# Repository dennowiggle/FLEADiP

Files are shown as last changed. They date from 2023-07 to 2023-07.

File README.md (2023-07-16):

# FLEADiP
FLEADiP is a compatiable add-on board for the Z80 Retro! project.

## Description
This project is an FPGA Logic Engine And Display Processor add-on board that fits the form factor of the [Z80 Retro! project by John Winans](https://github.com/Z80-Retro).

It has VGA, HDMI, two Atari 2600 compatible joystick ports, and user I/O expansion pin headers. 

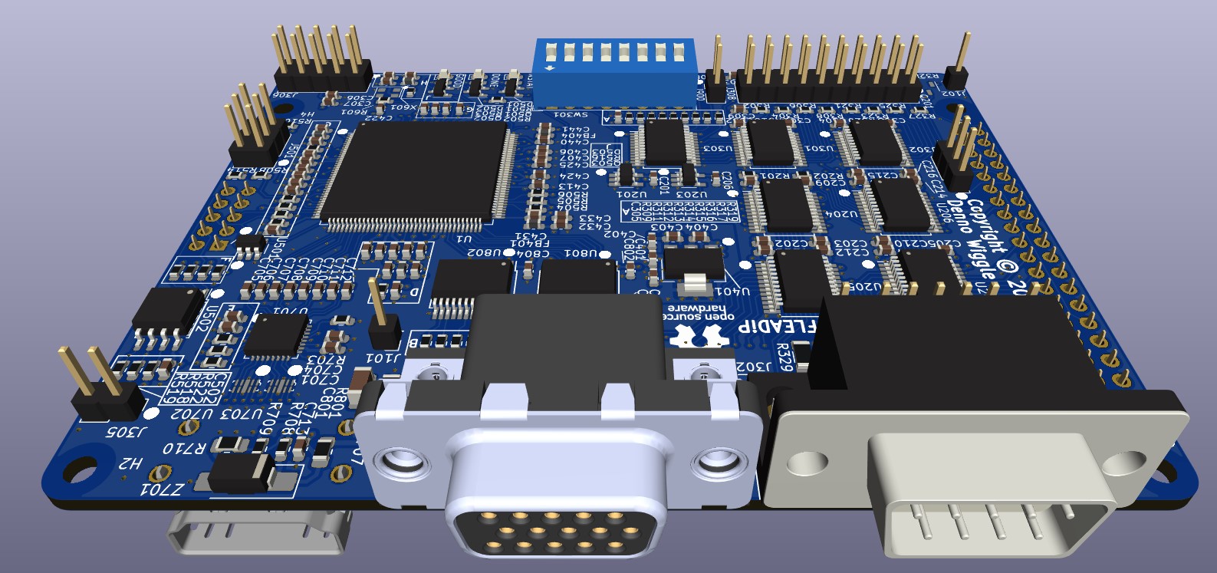
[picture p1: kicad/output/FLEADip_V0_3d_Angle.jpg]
FLEADiP Board Image FPGA Logic Engine And Video Processor


## Board design 
The board design is based around an Efinix Trion T20 FPGA in a QFP144 package. The HDMI output is driven by a PTN3366 IC that converts the LVDS from the FPGA into a true TMDS signal.

The VGA, HDMI, input header, and joystick ports are completely buffered to protect the FPGA. The user I/O port is unbuffered to give plenty of options for add-on creations.

The HDMI socket is on the back side of the board and allowance must be made for the type of board that is underneath. If there is not a good fit, a spacer board can be added.

## FPGA logic
The FPGA logic uses [Matthew Hagerty's F18A core](https://github.com/dnotq/f18a) so that code is compatible with the Z80 Retro! [2068-Z80-TMS9118 project board](https://github.com/Z80-Retro/2068-Z80-TMS9118). 

The HDMI logic on the FPGA uses the DVI code design from [Randi Rossi's VicII-Kawari project](https://github.com/randyrossi/vicii-kawari).

The FPGA image is stored on a 4MByte W25Q32JVSS Flash memory. There is both a SPI and JTAG programming header on the right side of the board. The board may be programmed using an FT232H module with the Efinix Efinity Progrrammer tool, or using another Z80 Retro! add on board, the - ESP32 Interface and Programmer with WiFi board (link coming) which was designed to fit below this one (no HDMI connector fit concerns).

A Trion FPGA with part number T20Q144C3 was used for bringup and testing of FLEADiP rev 0. This was a C3 timing part. A C4 or I4 part is preferred as they provide improved timing margin.

# Z80 I/O Port Addresses
| I/O Address | Function |
|---|---|
| 0x50 | FPGA address register address |
| 0x51 | FPGA data registers (not all are writable)  |
| 0x80 | Video Display Processor |
| 0x81 | Video Display Processor |
| 0xA8 | Joystick 0 (Z80 Retro! legacy address) |
| 0xA9 | Joystick 1 (Z80 Retro! legacy address) |

# FPGA Registers
Full details listed [in the VHDL code](fpga/src/wtm/wtm_z80Interface.vhd)
| Register Address  | Register Function | Read / Write |
|---|---| --- |
| 0 | FPGA Version | R |
| 1 | R/W Test Register  | R/W |
| 2 | PLL Lock | R |
| 3 | Config switch | R |
| 4 | Joystick 0 | R |
| 5 | Joystick 1 | R |
| 6 | HDMI control | R/W |
| 6 | Interrupt | R |

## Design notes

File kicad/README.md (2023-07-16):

# FLEADiP
FLEADiP is a compatiable add-on board for the Z80 Retro! project

## Description
This project is an FPGA Logic Engine And Display Processor add-on board that fits the form factor of the [Z80 Retro! project by John Winans](https://github.com/Z80-Retro).

## Top View
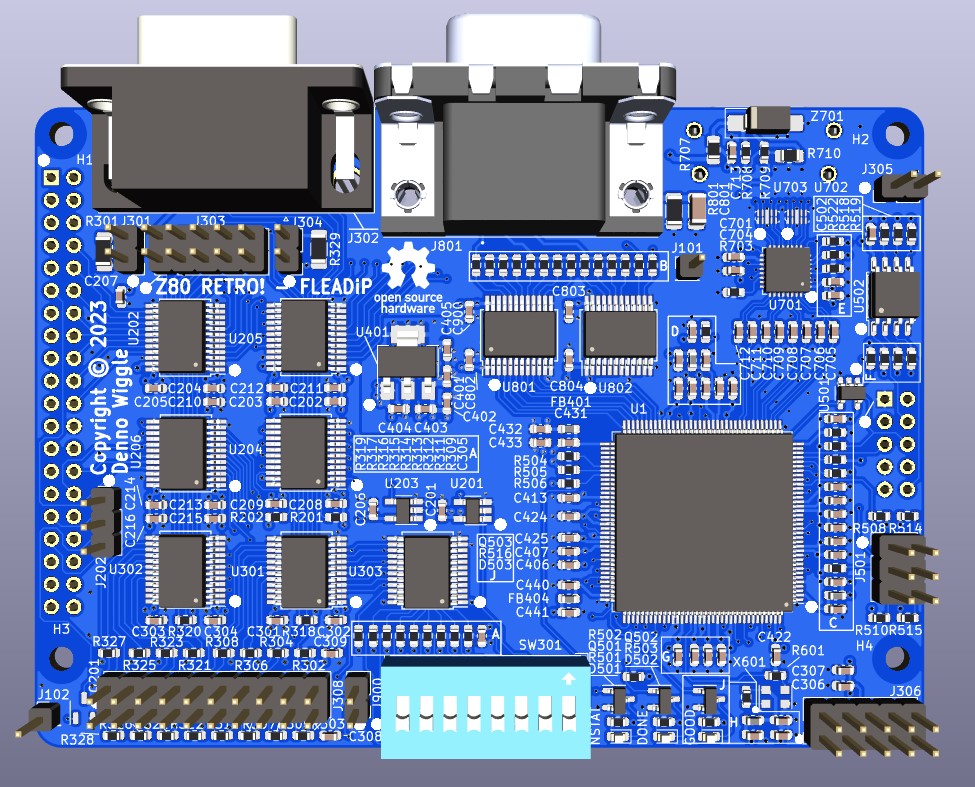
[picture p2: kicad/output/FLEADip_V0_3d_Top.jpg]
FLEADiP Top View Board Image Top View of FPGA Logic Engine And Video Processor


## Bottom View
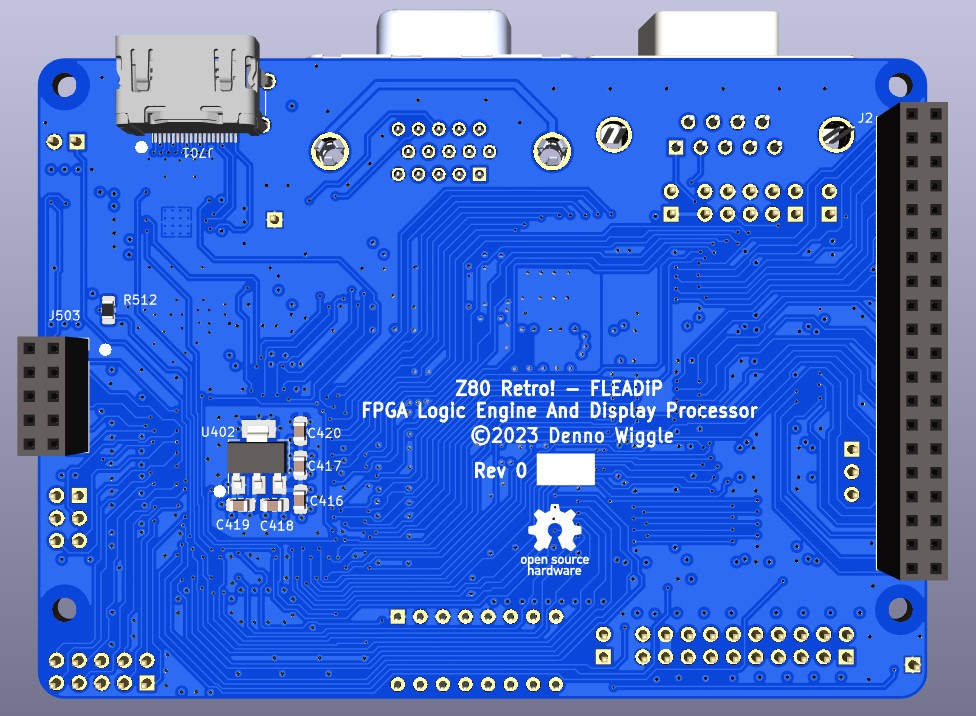
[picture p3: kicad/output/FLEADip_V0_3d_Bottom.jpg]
FLEADiP Bottom View Board Image Bottom View of FPGA Logic Engine And Video Processor


## FLEADiP Board Rev 0.0 Release Notes

1. The 'output' directory contains the BOM, netlist, and PDF schematic.

2. Board design used KiCad 7.0.2.

3. The HDMI connector is on the bottom side of the board so that there is no P/N signal swap, at least for rev 0 PCB. This means the card doesn't fit right above the Z80 Retro! CPU board unless a spacer board is added or the HDMI connector is not installed. The board was designed with the intent to use the ESP32 programmer board underneath FLEADiP which does have space for the connector.
   
   A future spin could move the HDMI connector to the top side, with swapping all P/N traces. This may work right away with no hdl code change, but if it does not the logic should be inverted in the HDL code to address this.
   
4. The silkscreen circle pin 1 marker for SW301, the 16 pin configuration switch is in the wrong position. The copper layout is fine, 
    - pin 1 is in the opposite corner to that marked - top right as viewed from the front board edge.

5. J503 2x5 right-angle programming connector should be installed on the top side of the board.
   - The silkscreen is marked on the back side, opposite to where the connector should be installed on.
   - The Bottom Side View image shows a vertical receptacle connector installed when it is in fact a right-angle header on the Top Side.

7. To program an image to the FPGA FLASH you can use a FT232H module with the Efinity FPGA SW tool programmer. 
   - I tested a $12 one from Amazon  https://www.amazon.com/dp/B09XTF7C1P:
   - Pin connections are as follows:

| Signal |  FT232H Module Pin  | FLEADiP Location |
| --- | --- | --- |
| SPI_CLK | AD1 | J503.2 |
| SPI_MOSI | AD0 | J503.8 |
| SPI_MISO | AD2 | J503.10 |
| SPI_CS_N | AD3 | J503.4 |
| MOUSE_RESET_N | AD4 | J503.6 |
| MOUSE_CDONE | AD5 | J503.5 |
| GND | Module Specific | J503.9 |
  
7. Efinity Programmer tool settings
    - With the FT232H module the USB target should be USB <-> Serial Convertor
    - Active mode
    - Starting address 0x0
    - Check erase before programming
    - Check verify after programming
    - Uses a hex file image
  
8. The board can also be programmed with the "ESP32 Programmer and WiFi" Z80 Retro! add on board which offers console xmodem and web based upload options for programming files.

9. The second Joystick port uses a 10 pin header J303 and is designed for a 10pin header to female DB9 cable with a gender 
   changer added. That way it's just using another Z80 Retro! console cable with addition of DB9 gender changer rather than 
   a totally new cable.
    - To use a 2x5 header to male DB9 cable the wires on the header need to swap pin columns.
      This method was tested with cable https://www.amazon.com/dp/B0BGQ96LX5

10. 1x2 pin headers that supply 5V if a jumper is installed on the joystick ports should be no stuff for normal operation.
    - If you want to supply 5V on DB9 pin 5 then soldering a wire is preferred as clearances of 1x2 to 2x5 headers are tight for DB9 cables made with IDC headers and 2 pin headers with jumpers installed.
    - To use a 2x5 cable with 1x2 jumpers installed use a 2x5 to DB9 cable with a narrow 2x5 receptacle. 
    - J301, J305 = no stuff for normal use.

11. The second joystick fire/button2 and 5V options are wired per MSX joystick form factor. 
     - Do not plug another type of 2 button joystick such as for C64 or Atari 
       especially if 5V is expected on a pin other than pin 5.
     - One button Atari 2600 compatible joysticks are supported.

12. The schematic design and BOM uses a T20QFP144 device with C3 timing. It is recommended to switch to a C4 part as it has significantly more timing margin in the logic design. DigiKey part number is 2134-T20Q144C4-ND. An I4 device is also a good choice .

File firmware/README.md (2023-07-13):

# Test Program

A simple Z80 assembly test program to access the FLEADiP FPGA registers.

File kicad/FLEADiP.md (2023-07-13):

# FLEADiP.kicad_sch

## 7/9/2023 3:29:13 PM

## Eeschema 7.0.2

## Component Count:224

Ref | Qty | Value | Digikey | Datasheet | Description
----|-----|-------|---------|-----------|------------
C201, C204, C205, C206, C208, C209, C211, C212, C213, C214, C301, C302, C303, C304, C305, C306, C308, C403, C404, C407, C408, C409, C410, C411, C412, C413, C414, C415, C422, C423, C424, C425, C426, C427, C428, C429, C430, C431, C432, C435, C437, C438, C439, C440, C441, C501, C502, C601, C602, C701, C703, C705, C706, C707, C708, C709, C710, C711, C712, C713, C802, C803, C900 | 63 | 100nF | 311-1088-1-ND | https://www.yageo.com/upload/media/product/productsearch/datasheet/mlcc/UPY-GPHC_X7R_6.3V-to-250V_22.pdf | Unpolarized capacitor, small symbol
C202, C203, C207, C210, C215, C216, C307, C309, C401, C402, C405, C406, C421, C433, C434, C436, C603, C702, C704, C804 | 20 | 10uF | 311-1782-1-ND | https://www.yageo.com/upload/media/product/productsearch/datasheet/mlcc/UPY-GPHC_X5R_4V-to-50V_26.pdf | Unpolarized capacitor, small symbol
C416, C417, C420 | 3 | 10uF | 1276-6455-1-ND | https://media.digikey.com/pdf/Data%20Sheets/Samsung%20PDFs/CL21A106KOQNNNG_Spec.pdf | Unpolarized capacitor, small symbol
C418, C419 | 2 | 100nF | 732-8045-1-ND | https://www.we-online.com/katalog/datasheet/885012207045.pdf | Unpolarized capacitor, small symbol
C801 | 1 | 1nF | 709-VPDD202W102K1GV001ECT-ND | https://www.johansondielectrics.com/downloads/catalog/johanson-dielectrics-product-catalog.pdf | Unpolarized capacitor, small symbol
D501, D502, D503 | 3 | LTST-C191KRKT | 160-1443-1-ND | http://optoelectronics.liteon.com/upload/download/DS22-2000-223/LTST-C191KRKT.PDF | LED RED CLEAR SMD
FB401, FB402, FB403, FB404, FB601 | 5 | BLM18AG601SN1D | 490-1014-1-ND | https://www.murata.com/en-us/products/productdata/8796738650142/ENFA0003.pdf | FERRITE BEAD 600 OHM 0603 1LN
H1, H2, H3, H4 | 4 | MountingHole |  | ~ | Mounting Hole without connection
J2 | 1 | Conn_02x20_Counter_Clockwise |  | https://www.amazon.com/gp/product/B084Q4W1PW/ref=ppx_yo_dt_b_search_asin_title?ie=UTF8&psc=1 | Generic connector, double row, 02x20, counter clockwise pin numbering scheme (similar to DIP package numbering), script generated (kicad-library-utils/schlib/autogen/connector/)
J101, J102 | 2 | Conn_01x01 |  | ~ | Generic connector, single row, 01x01, script generated (kicad-library-utils/schlib/autogen/connector/)
J202 | 1 | Conn_01x03 | 2057-PH1-03-UA-ND | https://app.adam-tech.com/products/download/data_sheet/201605/ph1-xx-ua-data-sheet.pdf | Generic connector, single row, 01x03, script generated (kicad-library-utils/schlib/autogen/connector/)
J301, J304, J305, J900 | 4 | Conn_01x02 | 2057-PH1-02-UA-ND | https://app.adam-tech.com/products/download/data_sheet/201605/ph1-xx-ua-data-sheet.pdf | Generic connector, single row, 01x02, script generated (kicad-library-utils/schlib/autogen/connector/)
J302 | 1 | DB9_Male_MountingHoles | AE10970-ND | http://www.assmann-wsw.com/uploads/datasheets/ASS_4888_CO.pdf | 
J303, J306 | 2 | Conn_02x05 | 1849-1002-ND | ~ | Generic connector, double row, 02x05, odd/even pin numbering scheme (row 1 odd numbers, row 2 even numbers), script generated (kicad-library-utils/schlib/autogen/connector/)
J308 | 1 | Conn_02x10_Odd_Even | 2057-PH2-20-UA-ND | https://app.adam-tech.com/products/download/data_sheet/202065/ph2-xx-ua-data-sheet.pdf | Generic connector, double row, 02x10, odd/even pin numbering scheme (row 1 odd numbers, row 2 even numbers), script generated (kicad-library-utils/schlib/autogen/connector/)
J501 | 1 | Conn_02x03 | 2057-PH2-06-UA-ND | https://app.adam-tech.com/products/download/data_sheet/202065/ph2-xx-ua-data-sheet.pdf | Generic connector, double row, 02x03, odd/even pin numbering scheme (row 1 odd numbers, row 2 even numbers), script generated (kicad-library-utils/schlib/autogen/connector/)
J503 | 1 | Conn_02x05_Right_Angle | 2057-PH2RA-10-UA-ND | https://app.adam-tech.com/products/download/data_sheet/200508/ph2ra-xx-ua-data-sheet.pdf | Generic connector, double row, 02x05, odd/even pin numbering scheme (row 1 odd numbers, row 2 even numbers), script generated (kicad-library-utils/schlib/autogen/connector/)
J701 | 1 | HDMI_A_1.4 | 609-4614-1-ND | https://www.amphenol-cs.com/media/wysiwyg/files/drawing/10029449.pdf | HDMI 1.4+ type A connector
J801 | 1 | ICD15S13E4GX00LF | 609-5181-ND | https://cdn.amphenol-cs.com/media/wysiwyg/files/drawing/c-cd-0012.pdf | 15-pin female receptacle socket D-SUB connector, High density (3 columns), Triple Row, Generic, VGA-connector, Mounting Hole
Q201, Q501, Q502, Q503 | 4 | MMUN2211LT1G | MMUN2211LT1GOSCT-ND | http://www.onsemi.com/pub/Collateral/DTC114E-D.PDF | TRANS PREBIAS NPN 246MW SOT23-3
R201, R202, R302, R303, R304, R305, R306, R307, R308, R309, R310, R311, R312, R313, R314, R315, R316, R317, R318, R319, R320, R321, R322, R323, R324, R325, R326, R327, R328, R504, R505, R506, R507, R508, R509, R510, R511, R513, R514, R515, R517, R518, R519, R520, R521, R522, R523, R602, R701, R702, R703, R708, R709 | 53 | 10K | 311-10KGRCT-ND | https://www.yageo.com/upload/media/product/productsearch/datasheet/rchip/PYu-RC_Group_51_RoHS_L_12.pdf | Resistor, US symbol
R301, R329 | 2 | 100R | 2019-RK73H2BTTD1000FCT-ND | https://www.yageo.com/upload/media/product/productsearch/datasheet/rchip/PYu-RC_Group_51_RoHS_L_12.pdf | Resistor, US symbol
R501, R502, R503, R516 | 4 | 1K | 311-1.00KHRCT-ND | https://www.yageo.com/upload/media/product/productsearch/datasheet/rchip/PYu-RC_Group_51_RoHS_L_12.pdf | Resistor, US symbol
R512 | 1 | 0R | 311-0.0ARCT-ND | https://www.yageo.com/upload/media/product/productsearch/datasheet/rchip/PYu-RC_Group_51_RoHS_L_12.pdf | Resistor, US symbol
R601, R705 | 2 | 33R | 13-RC0603FR-0733RLCT-ND | https://www.yageo.com/upload/media/product/productsearch/datasheet/rchip/PYu-RC_Group_51_RoHS_L_12.pdf | Resistor, US symbol
R704, R706 | 2 | 12K4 | 311-12.4KHRCT-ND | https://www.yageo.com/upload/media/product/productsearch/datasheet/rchip/PYu-RC_Group_51_RoHS_L_12.pdf | Resistor, US symbol
R707 | 1 | DNL | 311-0.0ARCT-ND | https://www.yageo.com/upload/media/product/productsearch/datasheet/rchip/PYu-RC_Group_51_RoHS_L_12.pdf | Resistor, US symbol
R710 | 1 | 2K7 | 311-2.7KARCT-ND | https://www.yageo.com/upload/media/product/productsearch/datasheet/rchip/PYu-RC_Group_51_RoHS_L_12.pdf | Resistor, US symbol
R801 | 1 | 1M | 311-1.0MERCT-ND | https://www.yageo.com/upload/media/product/productsearch/datasheet/rchip/PYu-RC_Group_51_RoHS_L_12.pdf | Resistor, US symbol
R802, R806, R810 | 3 | 4K02 | 311-4.02KHRCT-ND | https://www.yageo.com/upload/media/product/productsearch/datasheet/rchip/PYu-RC_Group_51_RoHS_L_12.pdf | Resistor, US symbol
R803, R807, R811 | 3 | 2K00 | 311-2.00KHRCT-ND | https://www.yageo.com/upload/media/product/productsearch/datasheet/rchip/PYu-RC_Group_51_RoHS_L_12.pdf | Resistor, US symbol
R804, R808, R812 | 3 | 1K00 | 311-1.00KHRCT-ND | https://www.yageo.com/upload/media/product/productsearch/datasheet/rchip/PYu-RC_Group_51_RoHS_L_12.pdf | Resistor, US symbol
R805, R809, R813 | 3 | 499R | RC0603FR-07499RL | https://www.yageo.com/upload/media/product/productsearch/datasheet/rchip/PYu-RC_Group_51_RoHS_L_12.pdf | Resistor, US symbol
R814, R815 | 2 | 100R | 311-100HRCT-ND | https://www.yageo.com/upload/media/product/productsearch/datasheet/rchip/PYu-RC_Group_51_RoHS_L_12.pdf | Resistor, US symbol
SW301 | 1 | SW_DIP_x08 | CT2068ST-ND | https://www.ctscorp.com/wp-content/uploads/206.pdf | 8x DIP Switch, Single Pole Single Throw (SPST) switch, small symbol
U1 | 1 | T20Q144C3 | 2134-T20Q144C3-ND | https://www.efinixinc.com/support/docsdl.php?s=ef&pn=DST20 | IC FPGA TRION T20 144QFP
U201, U203 | 2 | SN74LVC1G125DBVR | 296-11603-1-ND | http://www.ti.com/general/docs/suppproductinfo.tsp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 | IC BUF NON-INVERT 5.5V SOT23-5
U202, U204, U205, U206, U301, U302, U303, U801, U802 | 9 | SN74LVC8T245DBR | 296-21065-1-ND | https://www.ti.com/lit/ds/symlink/sn74lvc8t245.pdf | Octal BUS Transceivers, 3-State outputs
U401 | 1 | TLV1117LV33DCYR | 296-28778-1-ND | https://www.onsemi.com/pdf/datasheet/ncp1117lp-d.pdf | IC REG LINEAR 3.3V 1A SOT223
U402 | 1 | TLV1117LV12DCYR | 296-28776-1-ND | https://www.ti.com/lit/gpn/TLV1117LV | IC REG LINEAR 3.3V 1A SOT223
U501 | 1 | SN74LVC1G08DBVR | 296-11601-1-ND | http://www.ti.com/general/docs/suppproductinfo.tsp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 | IC GATE AND 1CH 2-INP SOT23-5
U502 | 1 | W25Q32JVSS | W25Q32JVSSIQCT-ND | http://www.winbond.com/resource-files/w25q32jv%20revg%2003272018%20plus.pdf | 32Mb Serial Flash Memory, Standard/Dual/Quad SPI, SOIC-8
U701 | 1 | PTN3366BSMP | 568-13387-1-ND | https://www.nxp.com/docs/en/data-sheet/PTN3366.pdf | IC VIDEO LEVEL SHIFTER 32HVQFN
U702, U703 | 2 | RCLAMP0524P | RCLAMP0524PCT-ND | https://semtech.my.salesforce.com/sfc/p/E0000000JelG/a/440000001MK2/k1amoKEAHshbxcc58ZeFJEDBUGCuP_6DIpLB6XG33.E | 
X601 | 1 | ECS-2333-500-BN-TR | XC1930CT-ND | https://ecsxtal.com/store/pdf/ecs-2325-2333.pdf | HCMOS Crystal Clock Oscillator, 2.5x2.0 mm SMD
Z701 | 1 | TVS_SMAJ5.0A | SMAJ5.0ALFCT-ND | https://www.littelfuse.com/~/media/electronics/datasheets/tvs_diodes/littelfuse_tvs_diode_smaj_datasheet.pdf | TVS DIODE 5VWM 9.2VC DO214AA

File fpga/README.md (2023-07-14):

# FPGA Code

Image files for programming in the [image directory](image).

Source files for synthesis in the [src directory](src).

Source hex file for initialising the 16K vram values that provide the power-on screen in the [init directory](init).

Efinix Efinity Synthesis and I/O configuration tool project files, and the license in this directory.

[F18A source code](https://github.com/dnotq/f18a) copyright 2011-2018 Matthew Hagerty.

[DVI source code](https://github.com/randyrossi/vicii-kawari) copyright (c) 2022 Randy Rossi.

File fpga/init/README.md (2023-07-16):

# Files to initialiase the 16K video ram

1. 16KRamInitF18aScreen.txt is a text file with 16,384 hex byte values extracted from the original [f18a 16k ram source file](../src/f18a/f18a_single_port_ram.vhd).
   - to use this file the VHDL source code should be changed so that the default background is white, and text is black. This is set by VDP register 7.

2. 16KRamZero.txt is a text file with 16,384 hex byte values all set to zero.

3. 16KRamInitZ80RetroLogo.txt is a "Z80 Retro!" logo created by SolderGirl from this [source](https://github.com/Stefanie80/CPM3_2063_Retro/blob/main/Firmware/rom.z80).

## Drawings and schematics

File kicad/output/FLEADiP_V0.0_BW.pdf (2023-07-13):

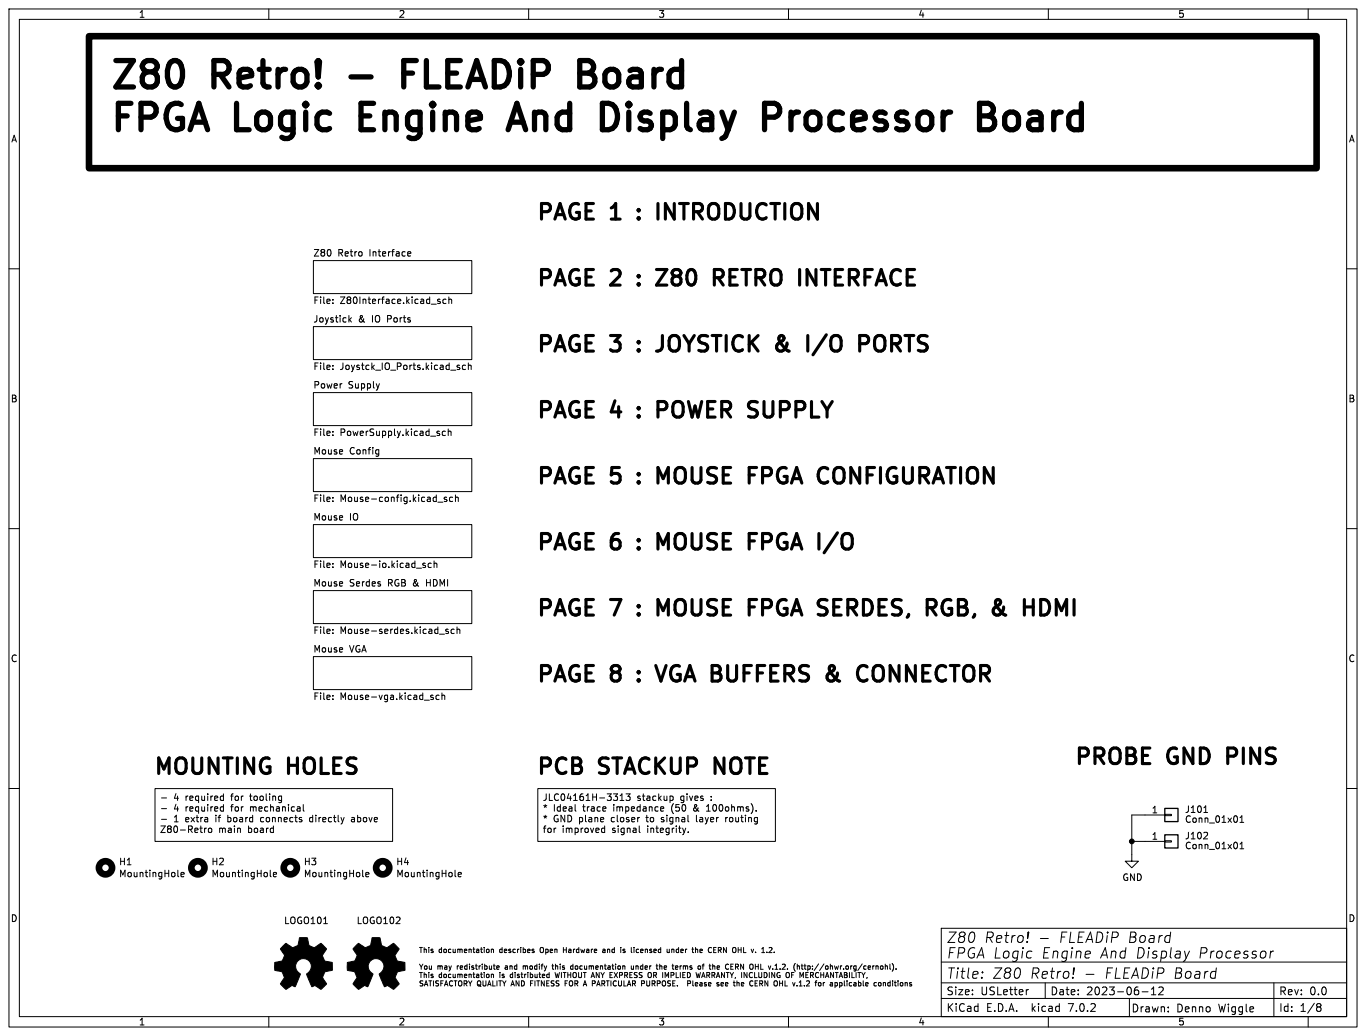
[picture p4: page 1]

Z80 Retro! - FLEADiP Board
FPGA Logic Engine And Display Processor Board

Joystick & IO Ports File: Joystck_IO_Ports.kicad_sch Power Supply File: PowerSupply.kicad_sch Z80 Retro Interface File: Z80Interface.kicad_sch

Mouse Config File: Mouse-config.kicad_sch Mouse Serdes RGB & HDMI File: Mouse-serdes.kicad_sch Mouse VGA

File: Mouse-vga.kicad_sch Mouse IO

PAGE 8 : VGA BUFFERS & CONNECTOR

for improved signal integrity. - 4 required for tooling

FPGA Logic Engine And Display Processor
Id: 1/8 Title: Z80 Retro! - FLEADiP Board

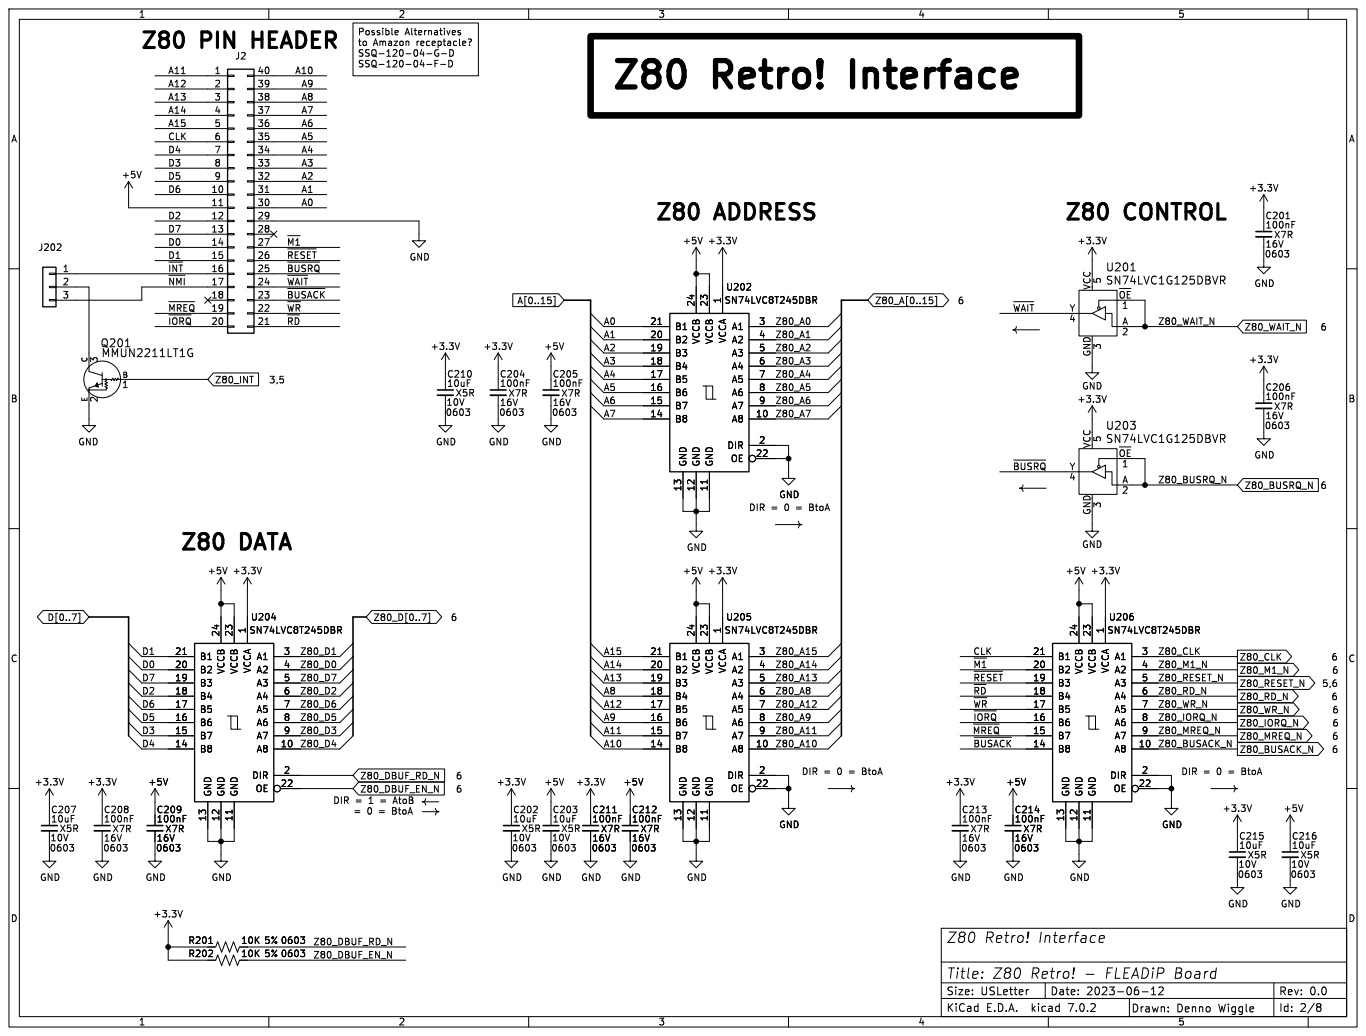
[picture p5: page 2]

Possible Alternatives
to Amazon receptacle? SSQ-120-04-G-D

1 A8 10 GND 11 GND 12 GND 13 B8 14 B7 15 B6 16 B5 17 B4 18 B3 19 DIR 2 B2 20 B1 21 OE 22 VCCB 23 VCCB 24 A1 3 A2 4 A3 5 A4 6 A5 7 A6 8 A7 9 U202 SN74LVC8T245DBR GND

1 A8 10 GND 11 GND 12 GND 13 B8 14 B7 15 B6 16 B5 17 B4 18 B3 19 DIR 2 B2 20 B1 21 OE 22 VCCB 23 VCCB 24 A1 3 A2 4 A3 5 A4 6 A5 7 A6 8 A7 9 +5VC214

1 A8 10 GND 11 GND 12 GND 13 B8 14 B7 15 B6 16 B5 17 B4 18 B3 19 DIR 2 B2 20 B1 21 OE 22 VCCB 23 VCCB 24 A1 3 A2 4 A3 5 A4 6 A5 7 A6 8 A7 9 U204 SN74LVC8T245DBR

1 A8 10 GND 11 GND 12 GND 13 B8 14 B7 15 B6 16 B5 17 B4 18 B3 19 DIR 2 B2 20 B1 21 OE 22 VCCB 23 VCCB 24 A1 3 A2 4 A3 5 A4 6 A5 7 A6 8 A7 9 U205 SN74LVC8T245DBR GND

1 A8 10 GND 11 GND 12 GND 13 B8 14 B7 15 B6 16 B5 17 B4 18 B3 19 DIR 2 B2 20 B1 21 OE 22 VCCB 23 VCCB 24 A1 3 A2 4 A3 5 A4 6 A5 7 A6 8 A7 9 U206 SN74LVC8T245DBR VCCA

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

1 A8 10 GND 11 GND 12 GND 13 B8 14 B7 15 B6 16 B5 17 B4 18 B3 19 DIR 2 B2 20 B1 21 OE 22 VCCB 23 VCCB 24 A1 3 A2 4 A3 5 A4 6 A5 7 A6 8 A7 9 +5V

1 A8 10 GND 11 GND 12 GND 13 B8 14 B7 15 B6 16 B5 17 B4 18 B3 19 DIR 2 B2 20 B1 21 OE 22 VCCB 23 VCCB 24 A1 3 A2 4 A3 5 A4 6 A5 7 A6 8 A7 9 GND

DIR = 0 = BtoA DIR = 1 = AtoB

Id: 2/8 Title: Z80 Retro! - FLEADiP Board

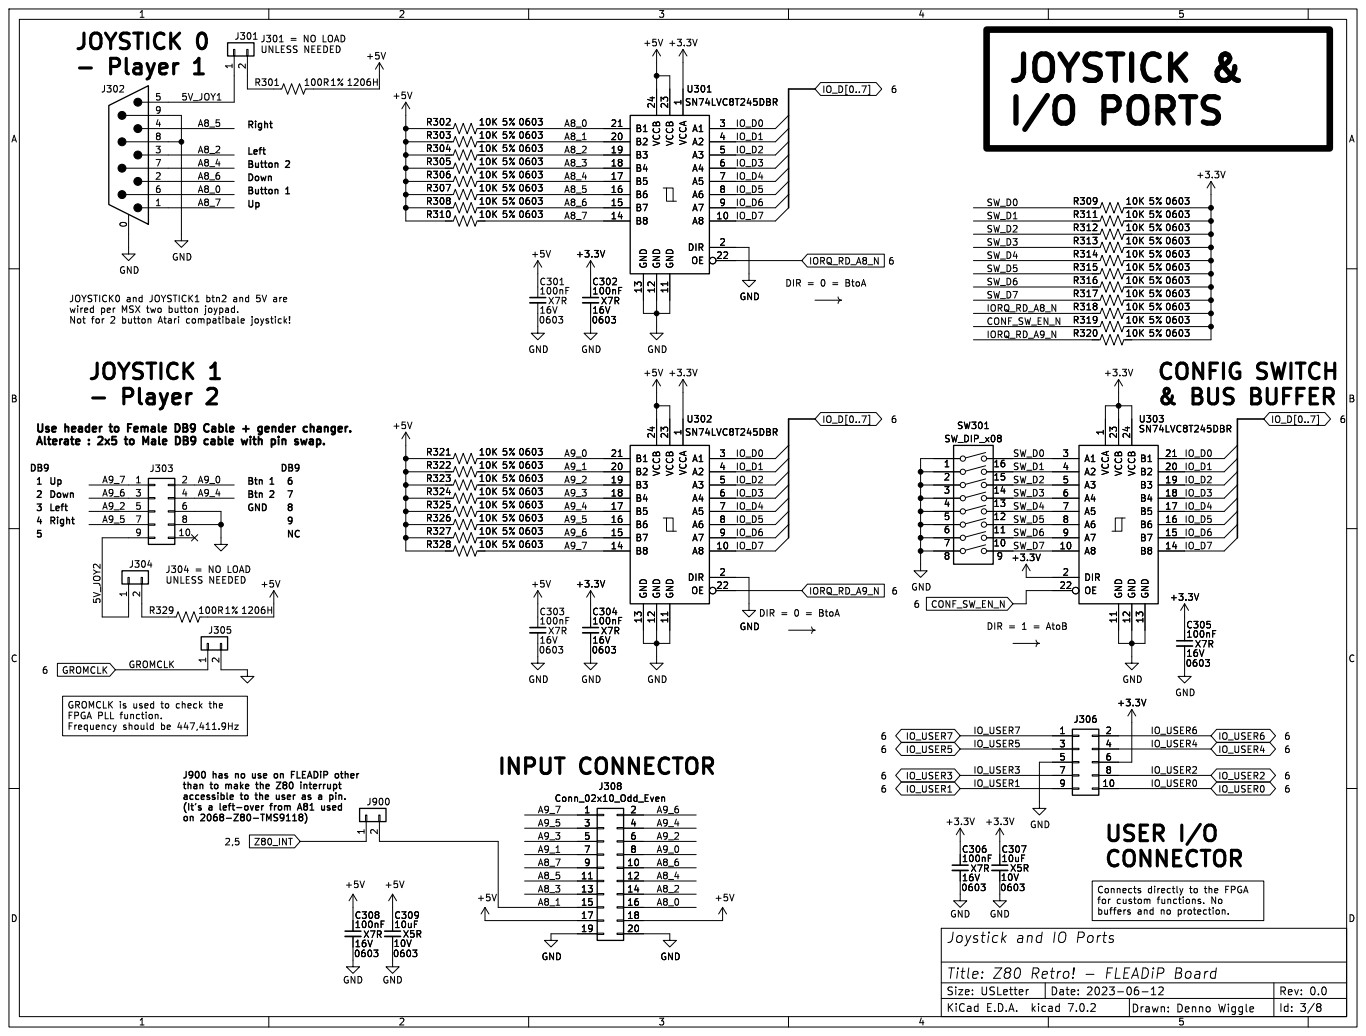
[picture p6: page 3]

Use header to Female DB9 Cable + gender changer. Alterate : 2x5 to Male DB9 cable with pin swap. JOYSTICK 0
- Player 1

1 A8 10 GND 11 GND 12 GND 13 B8 14 B7 15 B6 16 B5 17 B4 18 B3 19 DIR 2 B2 20 B1 21 OE 22 VCCB 23 VCCB 24 A1 3 A2 4 A3 5 A4 6 A5 7 A6 8 A7 9 U301 SN74LVC8T245DBR

1 A8 10 GND 11 GND 12 GND 13 B8 14 B7 15 B6 16 B5 17 B4 18 B3 19 DIR 2 B2 20 B1 21 OE 22 VCCB 23 VCCB 24 A1 3 A2 4 A3 5 A4 6 A5 7 A6 8 A7 9 +3.3V GND

1 A8 10 GND 11 GND 12 GND 13 B8 14 B7 15 B6 16 B5 17 B4 18 B3 19 DIR 2 B2 20 B1 21 OE 22 VCCB 23 VCCB 24 A1 3 A2 4 A3 5 A4 6 A5 7 A6 8 A7 9 U302 SN74LVC8T245DBR GND

1 A8 10 GND 11 GND 12 GND 13 B8 14 B7 15 B6 16 B5 17 B4 18 B3 19 DIR 2 B2 20 B1 21 OE 22 VCCB 23 VCCB 24 A1 3 A2 4 A3 5 A4 6 A5 7 A6 8 A7 9 U303 SN74LVC8T245DBR

1 A8 10 GND 11 GND 12 GND 13 B8 14 B7 15 B6 16 B5 17 B4 18 B3 19 DIR 2 B2 20 B1 21 OE 22 VCCB 23 VCCB 24 A1 3 A2 4 A3 5 A4 6 A5 7 A6 8 A7 9 +3.3VC304

1 A8 10 GND 11 GND 12 GND 13 B8 14 B7 15 B6 16 B5 17 B4 18 B3 19 DIR 2 B2 20 B1 21 OE 22 VCCB 23 VCCB 24 A1 3 A2 4 A3 5 A4 6 A5 7 A6 8 A7 9 +3.3VC305

buffers and no protection. GROMCLK is used to check the FPGA PLL function. Frequency should be 447,411.9Hz

J900 has no use on FLEADiP other
than to make the Z80 interrupt accessible to the user as a pin.

Joystick and IO Ports

Id: 3/8 Title: Z80 Retro! - FLEADiP Board

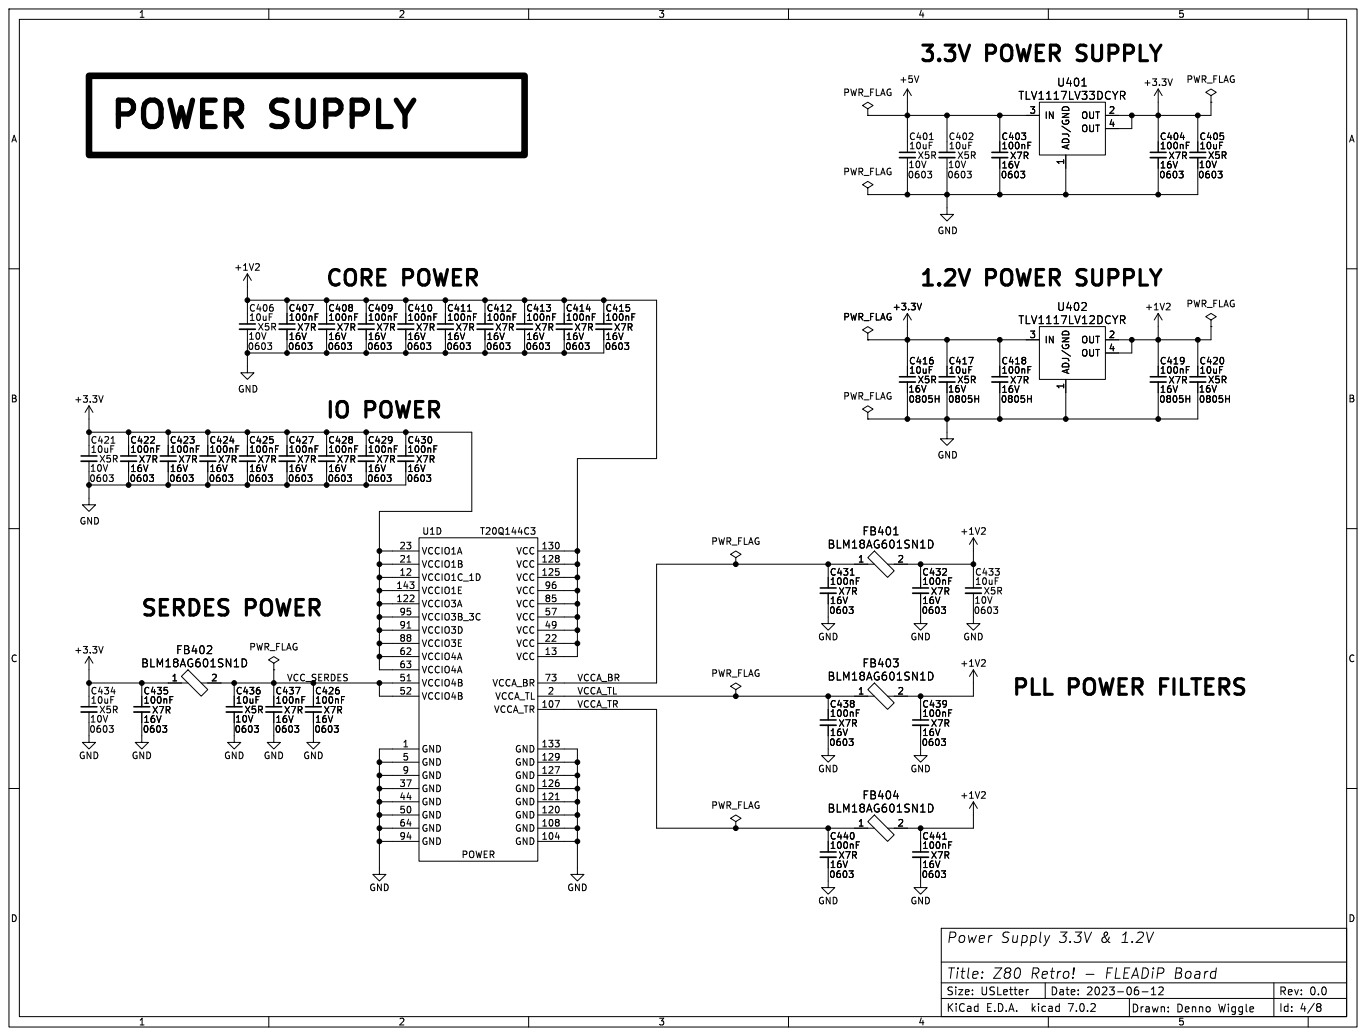
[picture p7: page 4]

Id: 4/8 Title: Z80 Retro! - FLEADiP Board

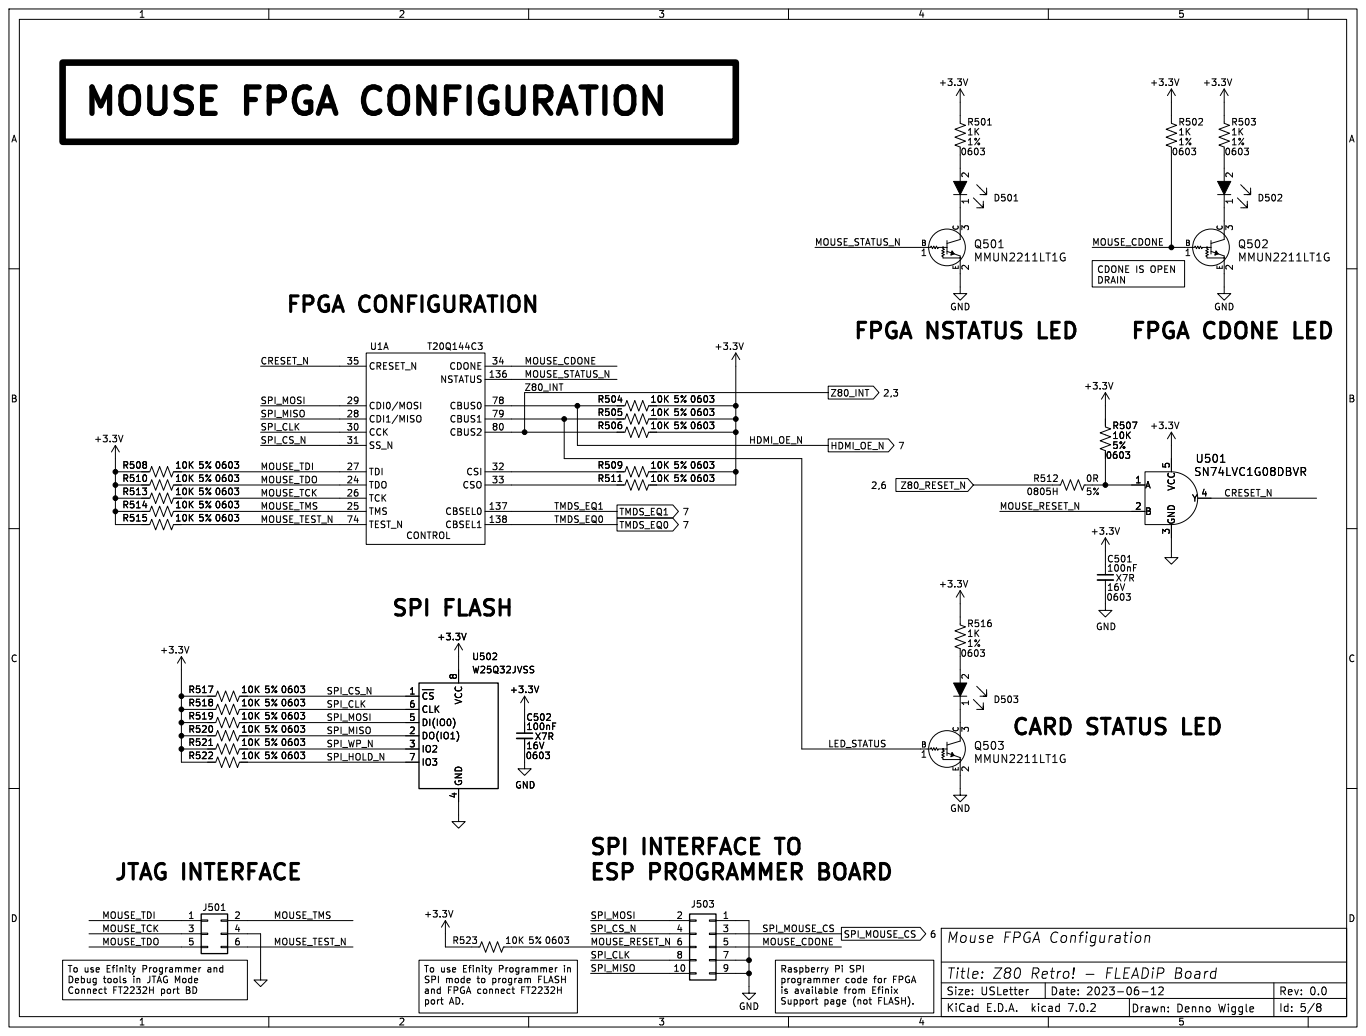
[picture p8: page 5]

Id: 5/8 Title: Z80 Retro! - FLEADiP Board

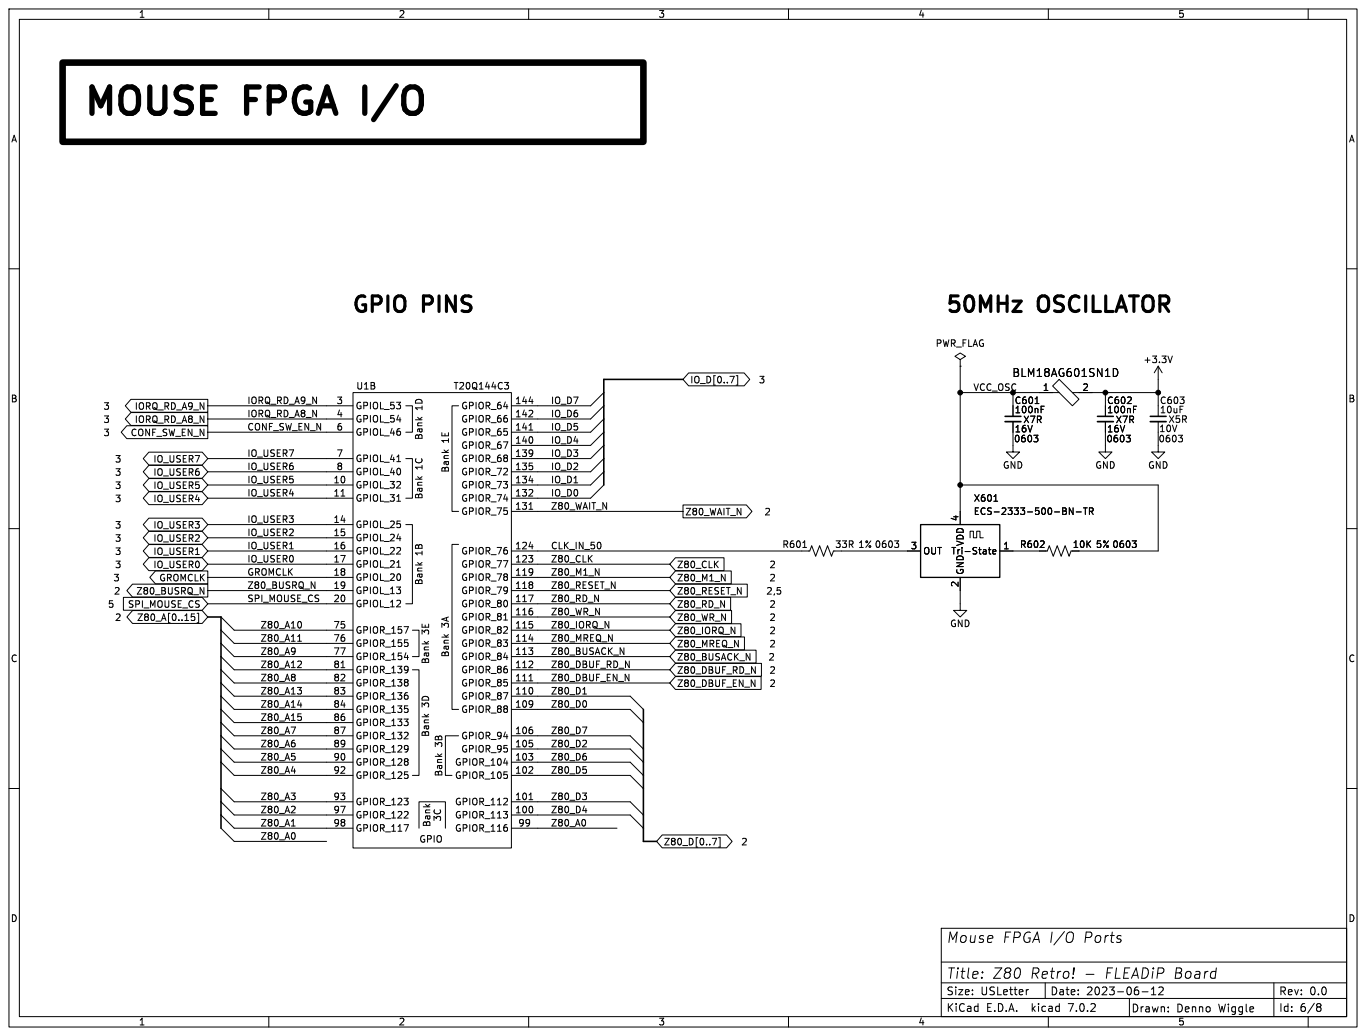
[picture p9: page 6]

3C Bank 1B Bank 1C Bank 1D Bank 1E Bank 3A Bank 3BBank 3D Bank 3E GPIO

Id: 6/8 Title: Z80 Retro! - FLEADiP Board

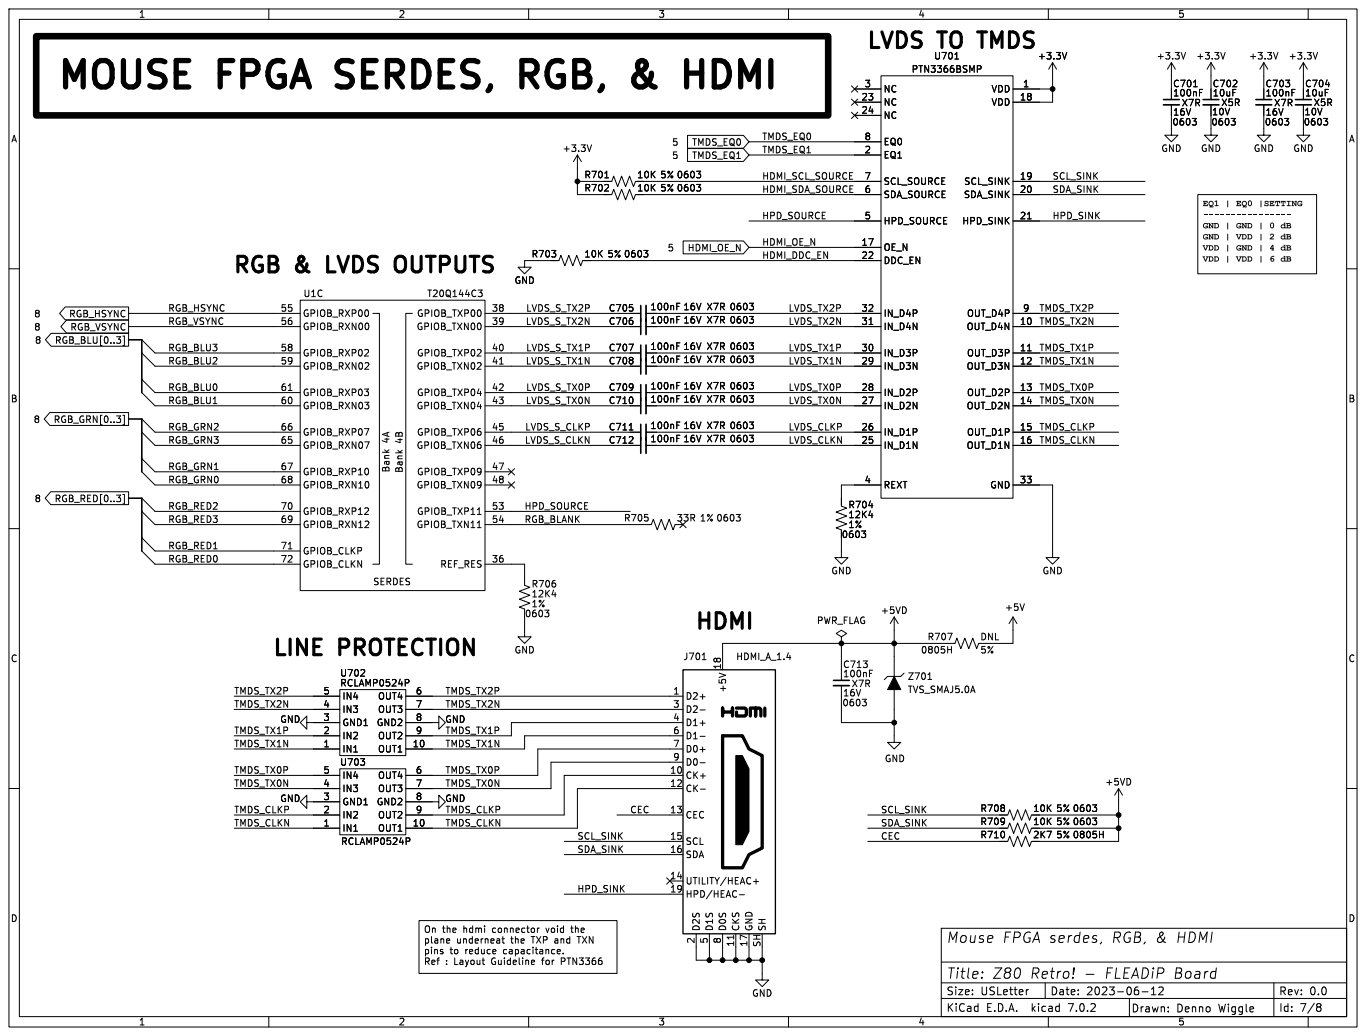
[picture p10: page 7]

pins to reduce capacitance. Ref : Layout Guideline for PTN3366 MOUSE FPGA SERDES, RGB, & HDMI

EQ1 | EQ0 |SETTING
---------------- GND | GND | 0 dB GND | VDD | 2 dB

Id: 7/8 Title: Z80 Retro! - FLEADiP Board

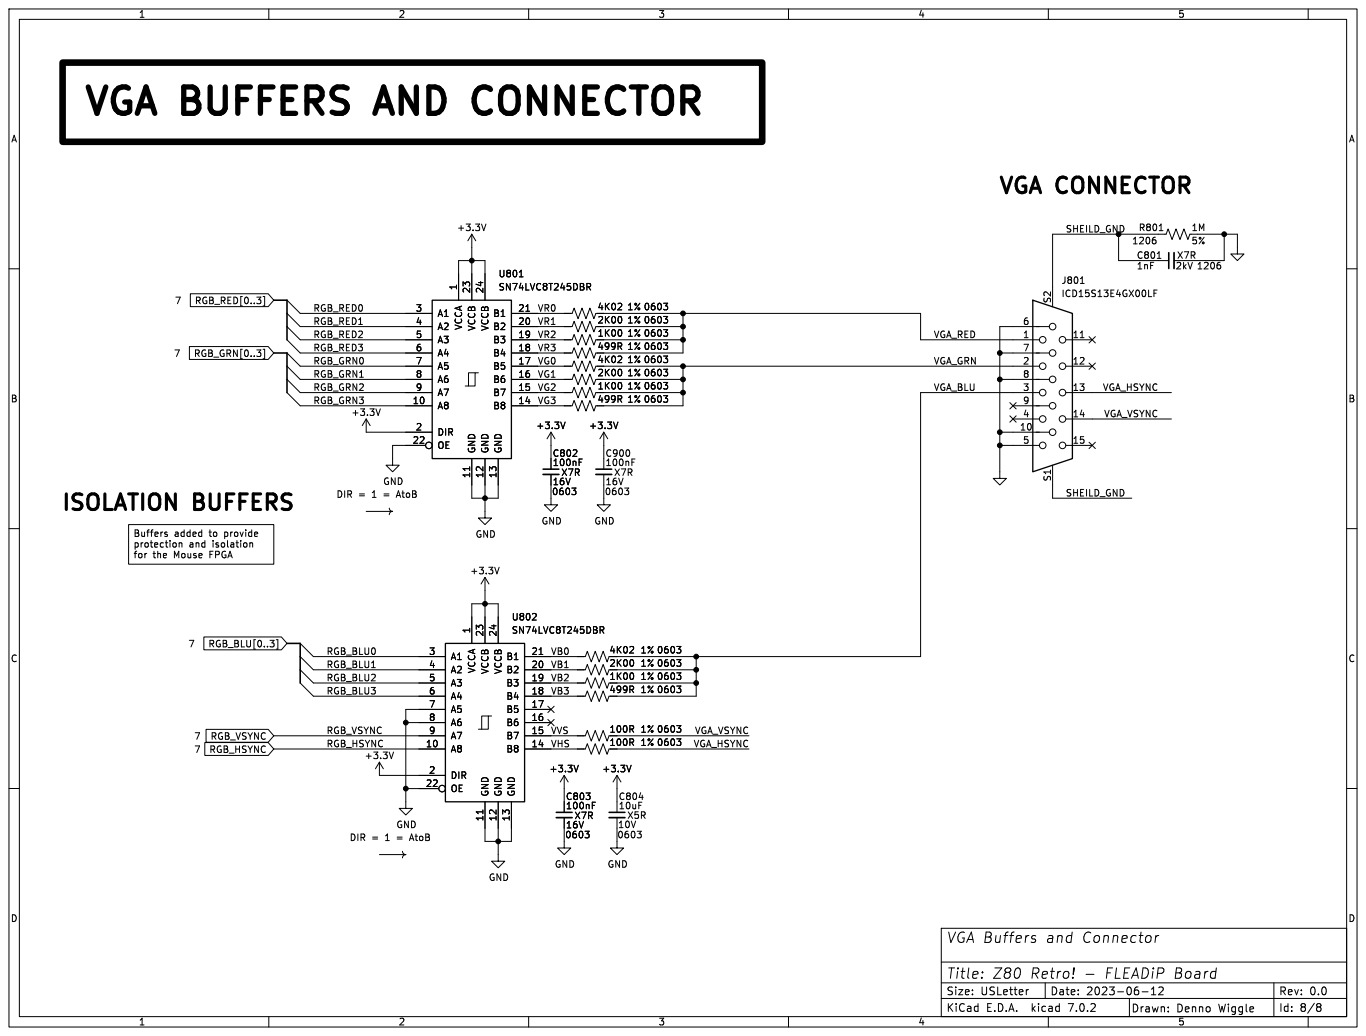
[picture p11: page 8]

for the Mouse FPGA VGA BUFFERS AND CONNECTOR
100R 1% 0603 +3.3V GND VCCA

1 A8 10 GND 11 GND 12 GND 13 B8 14 B7 15 B6 16 B5 17 B4 18 B3 19 DIR 2 B2 20 B1 21 OE 22 VCCB 23 VCCB 24 A1 3 A2 4 A3 5 A4 6 A5 7 A6 8 A7 9 U801 SN74LVC8T245DBR VCCA
ICD15S13E4GX00LF GND

1 A8 10 GND 11 GND 12 GND 13 B8 14 B7 15 B6 16 B5 17 B4 18 B3 19 DIR 2 B2 20 B1 21 OE 22 VCCB 23 VCCB 24 A1 3 A2 4 A3 5 A4 6 A5 7 A6 8 A7 9 +3.3V C803

RGB_BLU2 DIR = 1 = AtoB ISOLATION BUFFERS

Buffers added to provide

1 A8 10 GND 11 GND 12 GND 13 B8 14 B7 15 B6 16 B5 17 B4 18 B3 19 DIR 2 B2 20 B1 21 OE 22 VCCB 23 VCCB 24 A1 3 A2 4 A3 5 A4 6 A5 7 A6 8 A7 9 U802 SN74LVC8T245DBR
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

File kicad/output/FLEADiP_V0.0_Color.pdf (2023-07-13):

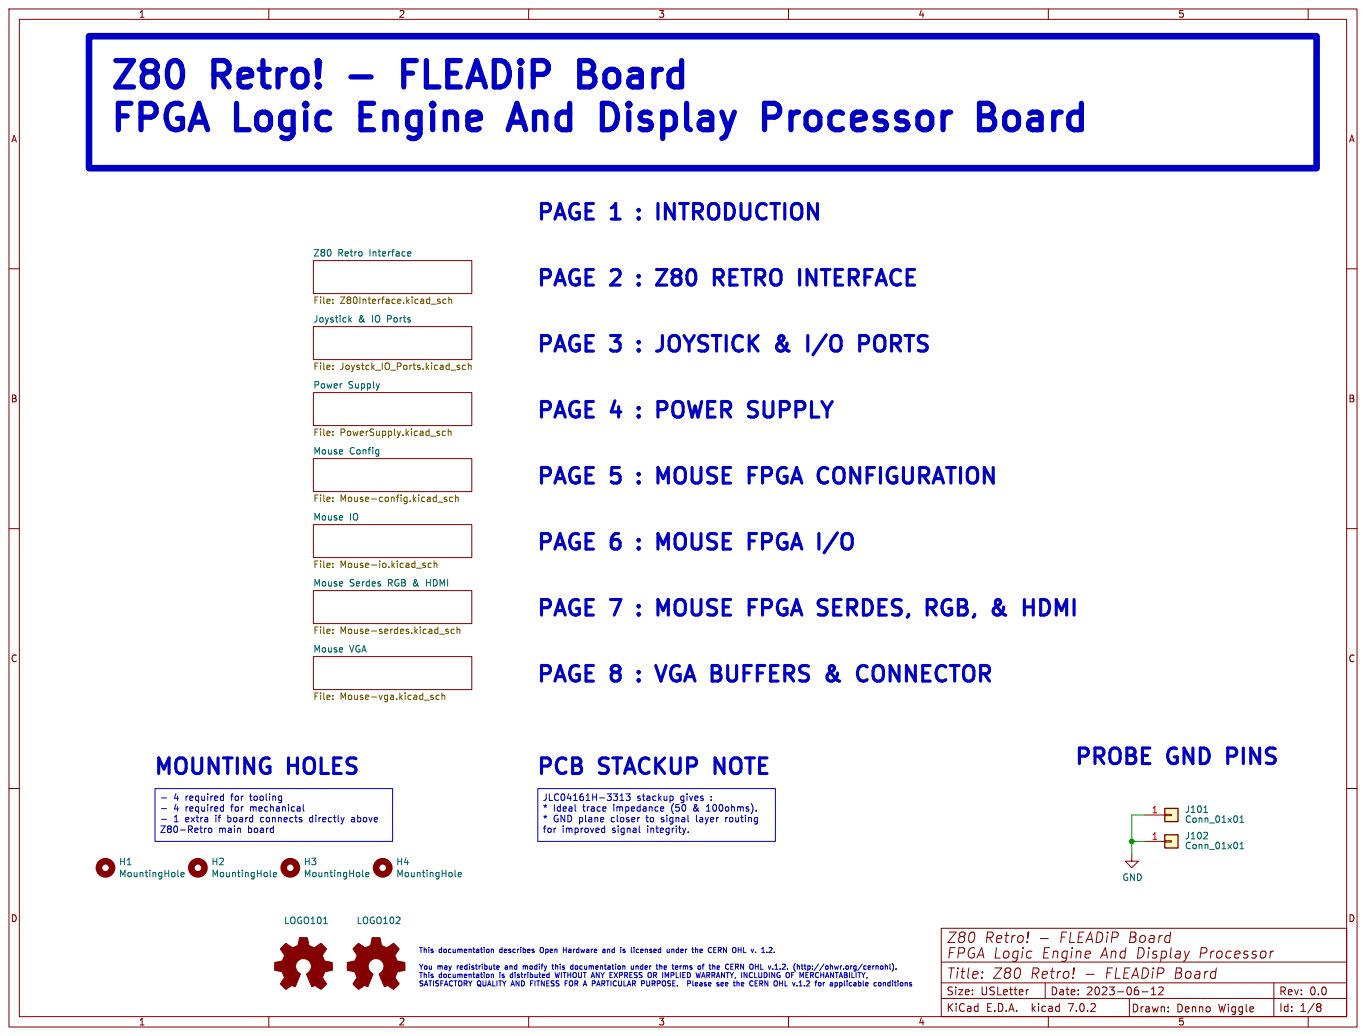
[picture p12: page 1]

Z80 Retro! - FLEADiP Board
FPGA Logic Engine And Display Processor Board

Joystick & IO Ports File: Joystck_IO_Ports.kicad_sch Power Supply File: PowerSupply.kicad_sch Z80 Retro Interface File: Z80Interface.kicad_sch

Mouse Config File: Mouse-config.kicad_sch Mouse Serdes RGB & HDMI File: Mouse-serdes.kicad_sch Mouse VGA

File: Mouse-vga.kicad_sch Mouse IO

PAGE 8 : VGA BUFFERS & CONNECTOR

for improved signal integrity. - 4 required for tooling

FPGA Logic Engine And Display Processor
Id: 1/8 Title: Z80 Retro! - FLEADiP Board

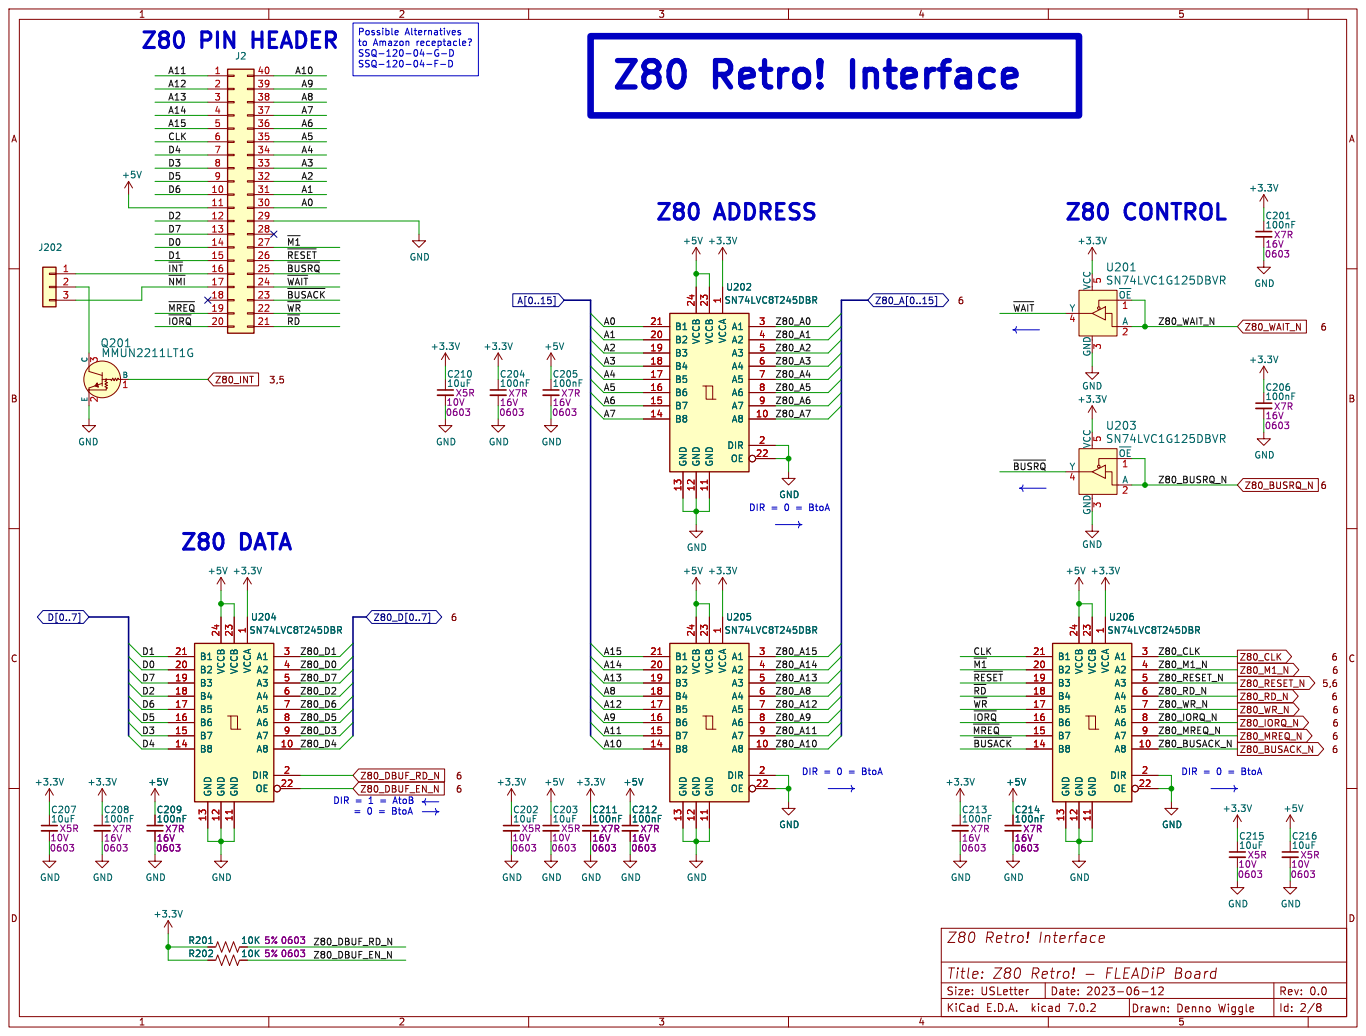
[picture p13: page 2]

Possible Alternatives
to Amazon receptacle? SSQ-120-04-G-D

1 A8 10 GND 11 GND 12 GND 13 B8 14 B7 15 B6 16 B5 17 B4 18 B3 19 DIR 2 B2 20 B1 21 OE 22 VCCB 23 VCCB 24 A1 3 A2 4 A3 5 A4 6 A5 7 A6 8 A7 9 U202 SN74LVC8T245DBR GND

1 A8 10 GND 11 GND 12 GND 13 B8 14 B7 15 B6 16 B5 17 B4 18 B3 19 DIR 2 B2 20 B1 21 OE 22 VCCB 23 VCCB 24 A1 3 A2 4 A3 5 A4 6 A5 7 A6 8 A7 9 C214

1 A8 10 GND 11 GND 12 GND 13 B8 14 B7 15 B6 16 B5 17 B4 18 B3 19 DIR 2 B2 20 B1 21 OE 22 VCCB 23 VCCB 24 A1 3 A2 4 A3 5 A4 6 A5 7 A6 8 A7 9 U204 SN74LVC8T245DBR

1 A8 10 GND 11 GND 12 GND 13 B8 14 B7 15 B6 16 B5 17 B4 18 B3 19 DIR 2 B2 20 B1 21 OE 22 VCCB 23 VCCB 24 A1 3 A2 4 A3 5 A4 6 A5 7 A6 8 A7 9 U205 SN74LVC8T245DBR

1 A8 10 GND 11 GND 12 GND 13 B8 14 B7 15 B6 16 B5 17 B4 18 B3 19 DIR 2 B2 20 B1 21 OE 22 VCCB 23 VCCB 24 A1 3 A2 4 A3 5 A4 6 A5 7 A6 8 A7 9 U206 SN74LVC8T245DBR VCCA

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

1 A8 10 GND 11 GND 12 GND 13 B8 14 B7 15 B6 16 B5 17 B4 18 B3 19 DIR 2 B2 20 B1 21 OE 22 VCCB 23 VCCB 24 A1 3 A2 4 A3 5 A4 6 A5 7 A6 8 A7 9 +5V

1 A8 10 GND 11 GND 12 GND 13 B8 14 B7 15 B6 16 B5 17 B4 18 B3 19 DIR 2 B2 20 B1 21 OE 22 VCCB 23 VCCB 24 A1 3 A2 4 A3 5 A4 6 A5 7 A6 8 A7 9 GND

DIR = 0 = BtoA DIR = 1 = AtoB

Id: 2/8 Title: Z80 Retro! - FLEADiP Board

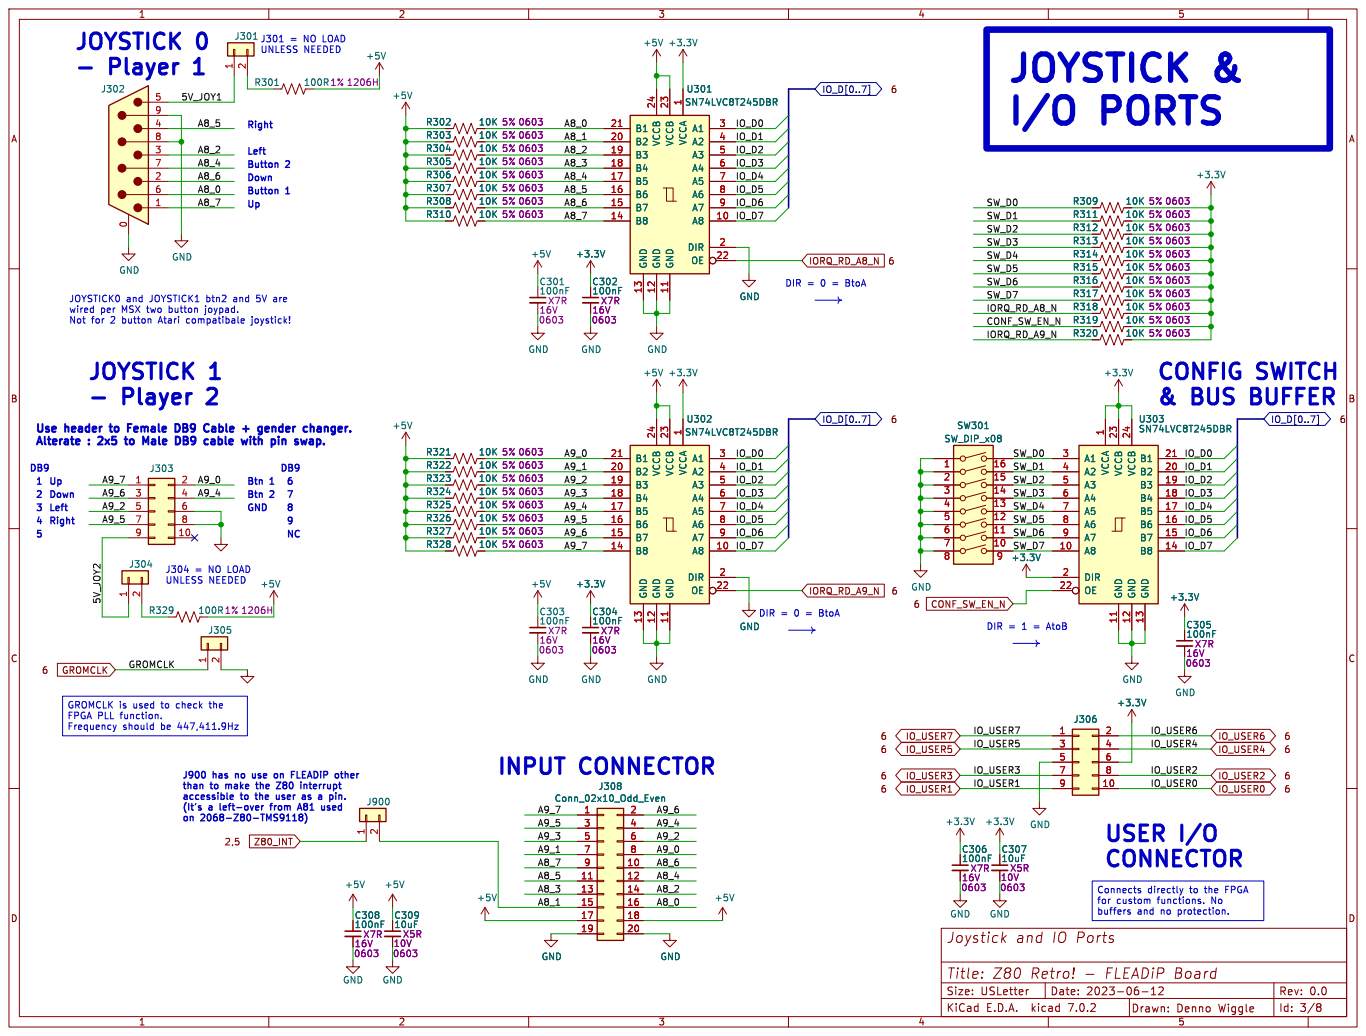
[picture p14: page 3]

5Use header to Female DB9 Cable + gender changer. Alterate : 2x5 to Male DB9 cable with pin swap. JOYSTICK 0
- Player 1

1 A8 10 GND 11 GND 12 GND 13 B8 14 B7 15 B6 16 B5 17 B4 18 B3 19 DIR 2 B2 20 B1 21 OE 22 VCCB 23 VCCB 24 A1 3 A2 4 A3 5 A4 6 A5 7 A6 8 A7 9 U301 SN74LVC8T245DBR

1 A8 10 GND 11 GND 12 GND 13 B8 14 B7 15 B6 16 B5 17 B4 18 B3 19 DIR 2 B2 20 B1 21 OE 22 VCCB 23 VCCB 24 A1 3 A2 4 A3 5 A4 6 A5 7 A6 8 A7 9 +3.3V GND
GND GND GND

1 A8 10 GND 11 GND 12 GND 13 B8 14 B7 15 B6 16 B5 17 B4 18 B3 19 DIR 2 B2 20 B1 21 OE 22 VCCB 23 VCCB 24 A1 3 A2 4 A3 5 A4 6 A5 7 A6 8 A7 9 U302 SN74LVC8T245DBR

1 A8 10 GND 11 GND 12 GND 13 B8 14 B7 15 B6 16 B5 17 B4 18 B3 19 DIR 2 B2 20 B1 21 OE 22 VCCB 23 VCCB 24 A1 3 A2 4 A3 5 A4 6 A5 7 A6 8 A7 9 U303 SN74LVC8T245DBR

1 A8 10 GND 11 GND 12 GND 13 B8 14 B7 15 B6 16 B5 17 B4 18 B3 19 DIR 2 B2 20 B1 21 OE 22 VCCB 23 VCCB 24 A1 3 A2 4 A3 5 A4 6 A5 7 A6 8 A7 9 +3.3VC304

1 A8 10 GND 11 GND 12 GND 13 B8 14 B7 15 B6 16 B5 17 B4 18 B3 19 DIR 2 B2 20 B1 21 OE 22 VCCB 23 VCCB 24 A1 3 A2 4 A3 5 A4 6 A5 7 A6 8 A7 9 +3.3VC305

buffers and no protection. GROMCLK is used to check the FPGA PLL function. Frequency should be 447,411.9Hz

J900 has no use on FLEADiP other
than to make the Z80 interrupt accessible to the user as a pin.

Joystick and IO Ports

Id: 3/8 Title: Z80 Retro! - FLEADiP Board

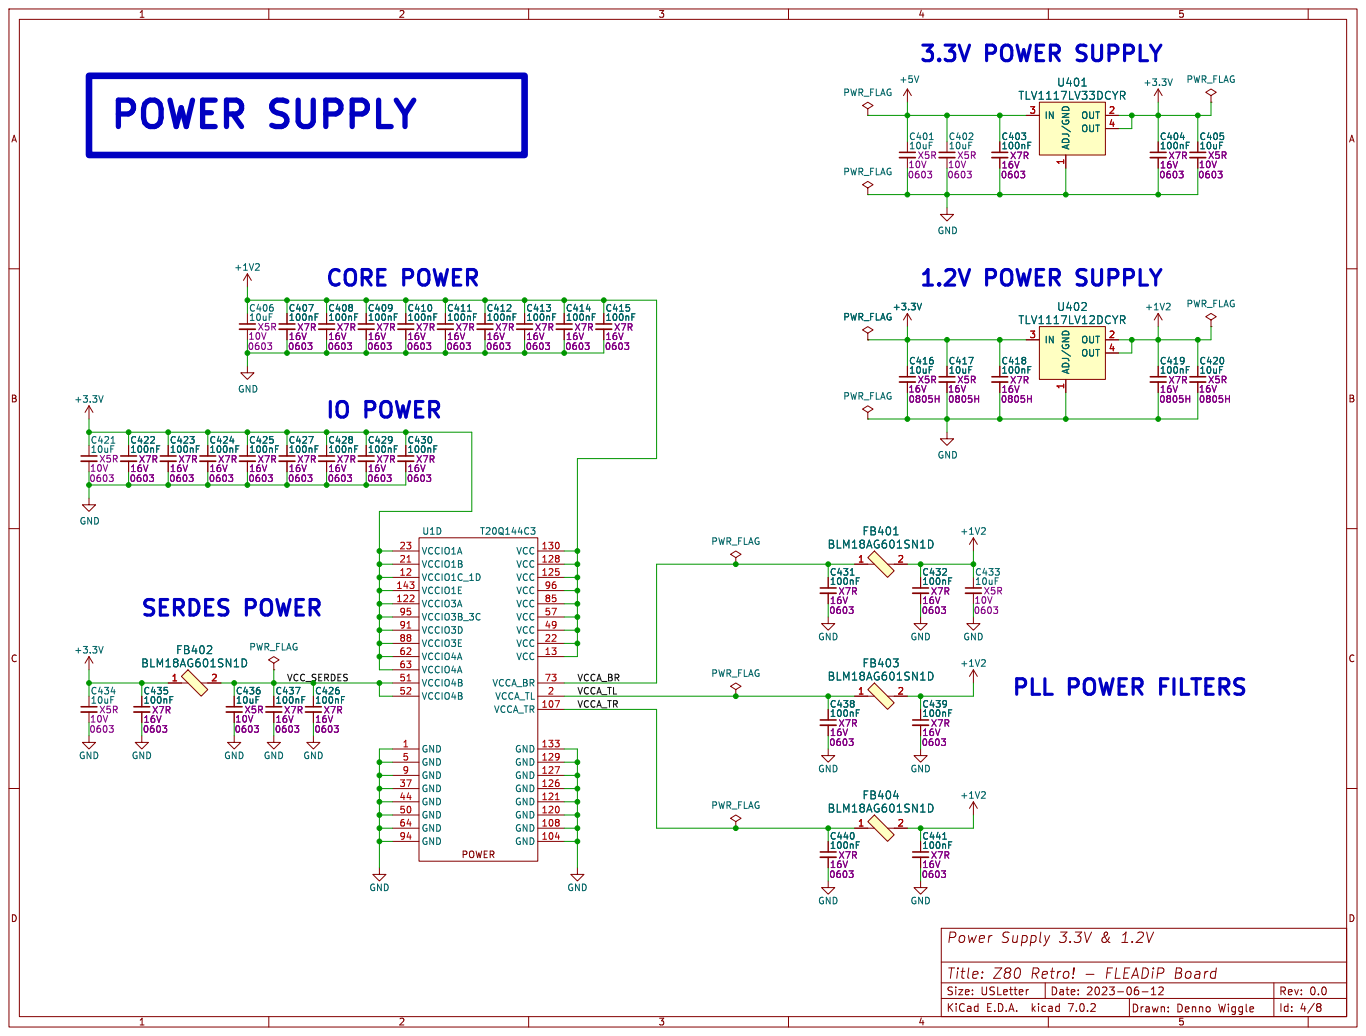
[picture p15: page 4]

Id: 4/8 Title: Z80 Retro! - FLEADiP Board


Id: 5/8 Title: Z80 Retro! - FLEADiP Board


3C Bank 1B Bank 1C Bank 1D Bank 1E Bank 3A Bank 3BBank 3D Bank 3E GPIO

Id: 6/8 Title: Z80 Retro! - FLEADiP Board


pins to reduce capacitance. Ref : Layout Guideline for PTN3366 MOUSE FPGA SERDES, RGB, & HDMI

EQ1 | EQ0 |SETTING
---------------- GND | GND | 0 dB GND | VDD | 2 dB

Id: 7/8 Title: Z80 Retro! - FLEADiP Board


VGA BUFFERS AND CONNECTOR

1 A8 10 GND 11 GND 12 GND 13 B8 14 B7 15 B6 16 B5 17 B4 18 B3 19 DIR 2 B2 20 B1 21 OE 22 VCCB 23 VCCB 24 A1 3 A2 4 A3 5 A4 6 A5 7 A6 8 A7 9 +3.3VC802

DIR = 1 = AtoB DIR = 1 = AtoB ISOLATION BUFFERS

Buffers added to provide
for the Mouse FPGA

1 A8 10 GND 11 GND 12 GND 13 B8 14 B7 15 B6 16 B5 17 B4 18 B3 19 DIR 2 B2 20 B1 21 OE 22 VCCB 23 VCCB 24 A1 3 A2 4 A3 5 A4 6 A5 7 A6 8 A7 9 U802 SN74LVC8T245DBR

1 A8 10 GND 11 GND 12 GND 13 B8 14 B7 15 B6 16 B5 17 B4 18 B3 19 DIR 2 B2 20 B1 21 OE 22 VCCB 23 VCCB 24 A1 3 A2 4 A3 5 A4 6 A5 7 A6 8 A7 9 +3.3V +3.3V

VGA Buffers and Connector
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
